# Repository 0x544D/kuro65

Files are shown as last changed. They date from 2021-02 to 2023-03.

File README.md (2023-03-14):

# Kuro65

The hot-swappable ISO mechanical keyboard PCB. 

Features include:
- QMK compatible
- Hot-swappable MX sockets
- 65% ISO DE layout
- Per-key RGB LED
- Multi-layer support

### Table of contents
- [Schematic](#schematic)
- [Bill of Material](#bom)
- [Pictures](#pictures)

# Schematic
<a name="schematic"/>
Standard schematic for a QMK firmware compatible mechanical keyboard.

#### Main schematic:
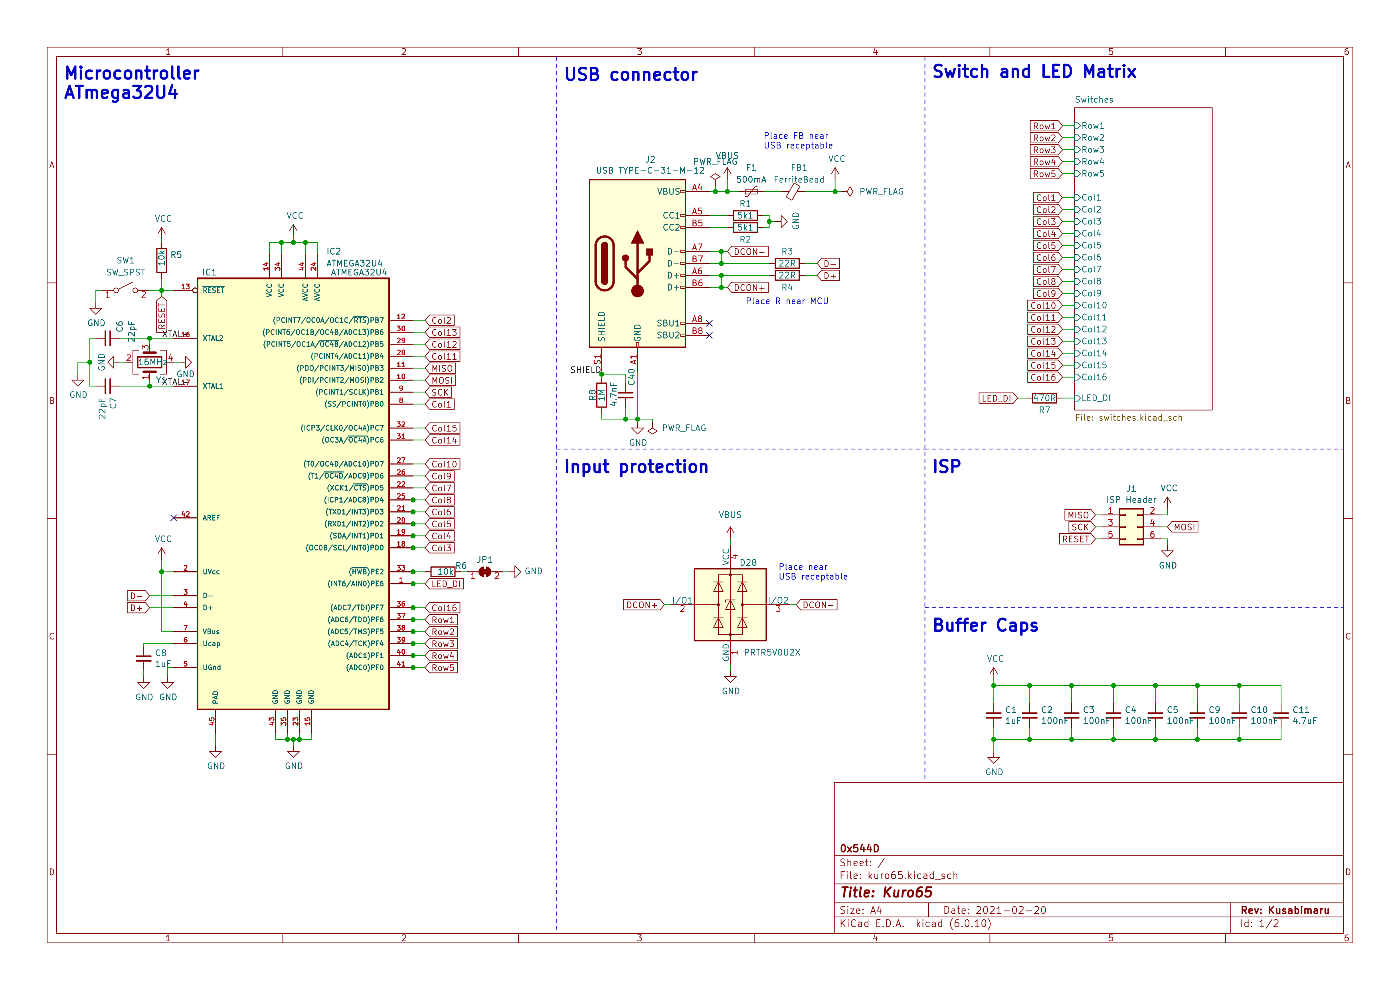
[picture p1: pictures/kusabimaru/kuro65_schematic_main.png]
schematic_main

#### Switch matrix schematic:
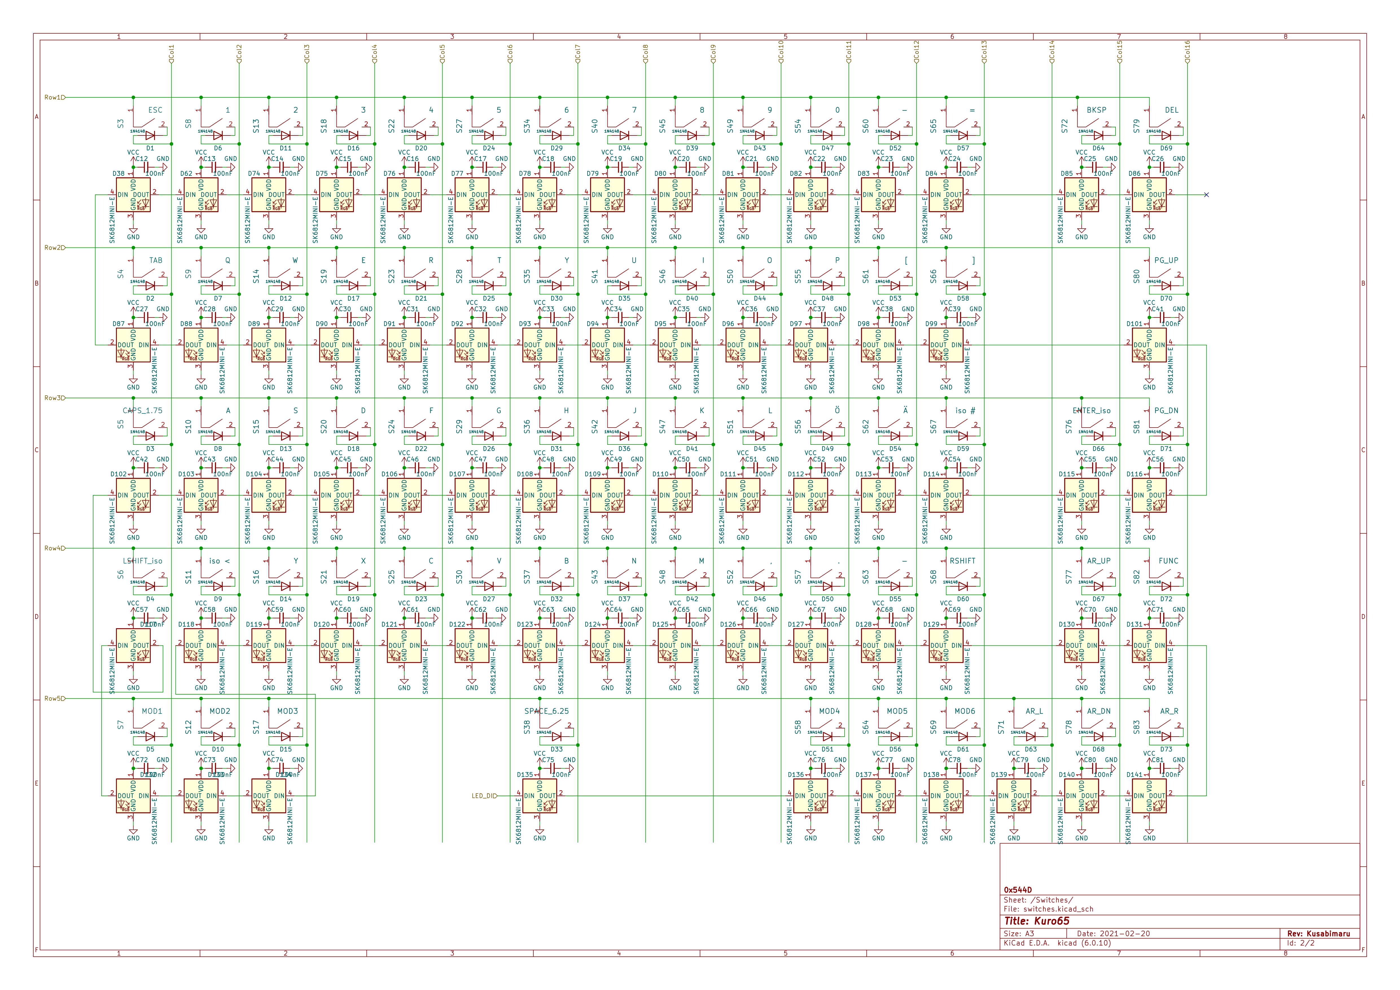
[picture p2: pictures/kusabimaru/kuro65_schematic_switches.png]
schematic_switches


# Bill of Material
<a name="bom"/>

| Qty | Component | Footprint | JLC Part Number | Datasheet | Shop URL |
|-----|---|---|---|---|---|
|  1  | ATMEGA32U4-MU | QFN-44_7x7x05P | C112161 |[Datasheet](https://datasheet.lcsc.com/lcsc/1809032024_Microchip-Tech-ATMEGA32U4-MU_C112161.pdf) | [Link](https://jlcpcb.com/partdetail/MicrochipTech-ATMEGA32U4MU/C112161) |
|  1  | X322516MLB4SI | SMD3225-4P | C13738 |[Datasheet](https://datasheet.lcsc.com/lcsc/2103291133_Yangxing-Tech-X322516MLB4SI_C13738.pdf) | [Link](https://jlcpcb.com/partdetail/YangxingTech-X322516MLB4SI/C13738) |
|  1  | B3FS-1000P | SMD,6x6x3.1mm  | C271750 |[Datasheet](https://omronfs.omron.com/en_US/ecb/products/pdf/en-b3fs.pdf) | [Link](https://jlcpcb.com/partdetail/OmronElectronics-B3FS1000P/C271750) |
|  1  | TYPE-C-31-M-12  | SMD | C165948 |[Datasheet](https://datasheet.lcsc.com/lcsc/2205251630_Korean-Hroparts-Elec-TYPE-C-31-M-12_C165948.pdf) | [Link](https://jlcpcb.com/partdetail/Korean_HropartsElec-TYPE_C_31_M12/C165948) |
| 70  | CPG151101S11 | SMD | C2803348 |[Datasheet](https://datasheet.lcsc.com/lcsc/2202281830_Kailh-CPG151101S11_C2803348.pdf) | [Link](https://jlcpcb.com/partdetail/Kailh-CPG151101S11/C2803348) |
| 70  | 1N4148W | SOD-123 | C109203 |[Datasheet](https://datasheet.lcsc.com/lcsc/1811131721_Shikues-1N4148W_C109203.pdf) | [Link](https://jlcpcb.com/partdetail/Shikues-1N4148W/C109203) |

# Pictures
<a name="pictures"/>

Kuro65 PCB
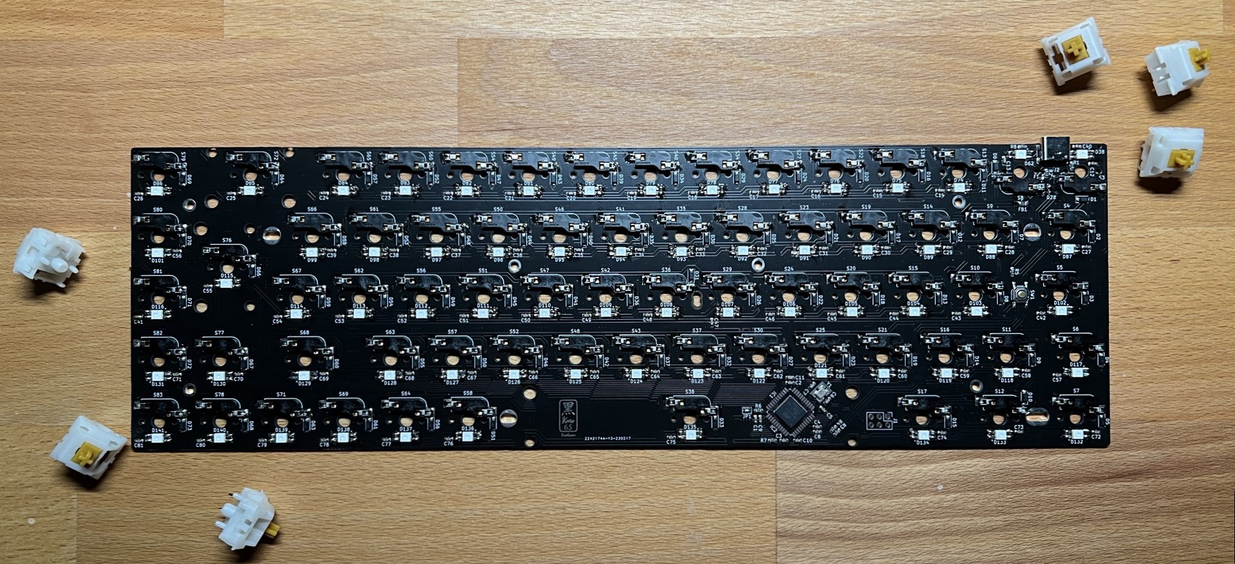
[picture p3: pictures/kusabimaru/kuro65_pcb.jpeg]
kuro65_pcb

Kuro65 inside TOFU65 case
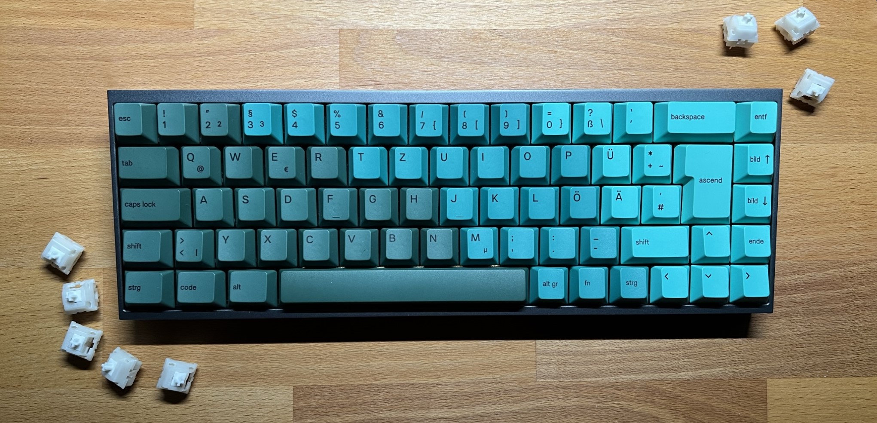
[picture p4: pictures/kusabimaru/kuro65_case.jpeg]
kuro65_case


# Contributors and Acknowledgements
- Keyswitches based on: [daprice](https://github.com/daprice/keyswitches.pretty)
- Stabilizers used: [perigoso](https://github.com/perigoso/Switch_Keyboard)

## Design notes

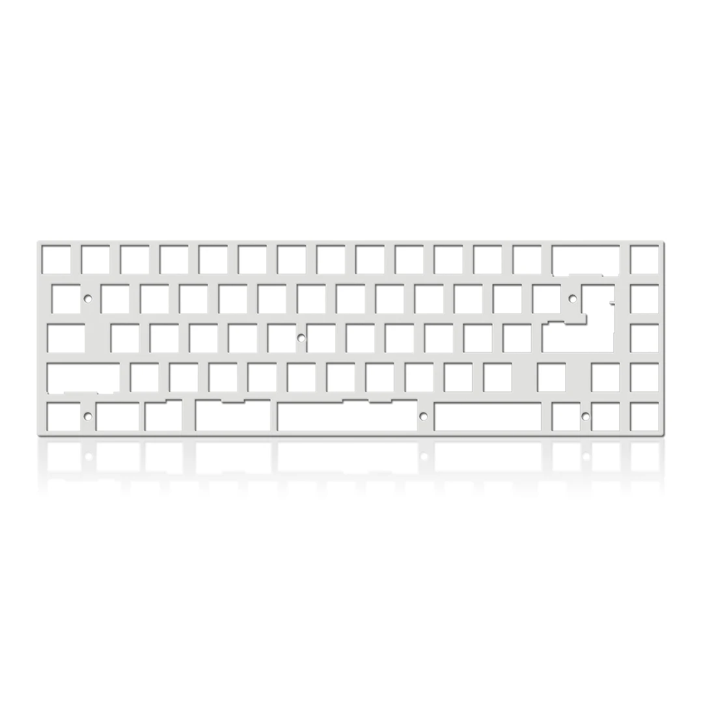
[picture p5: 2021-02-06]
references/65plate.webp

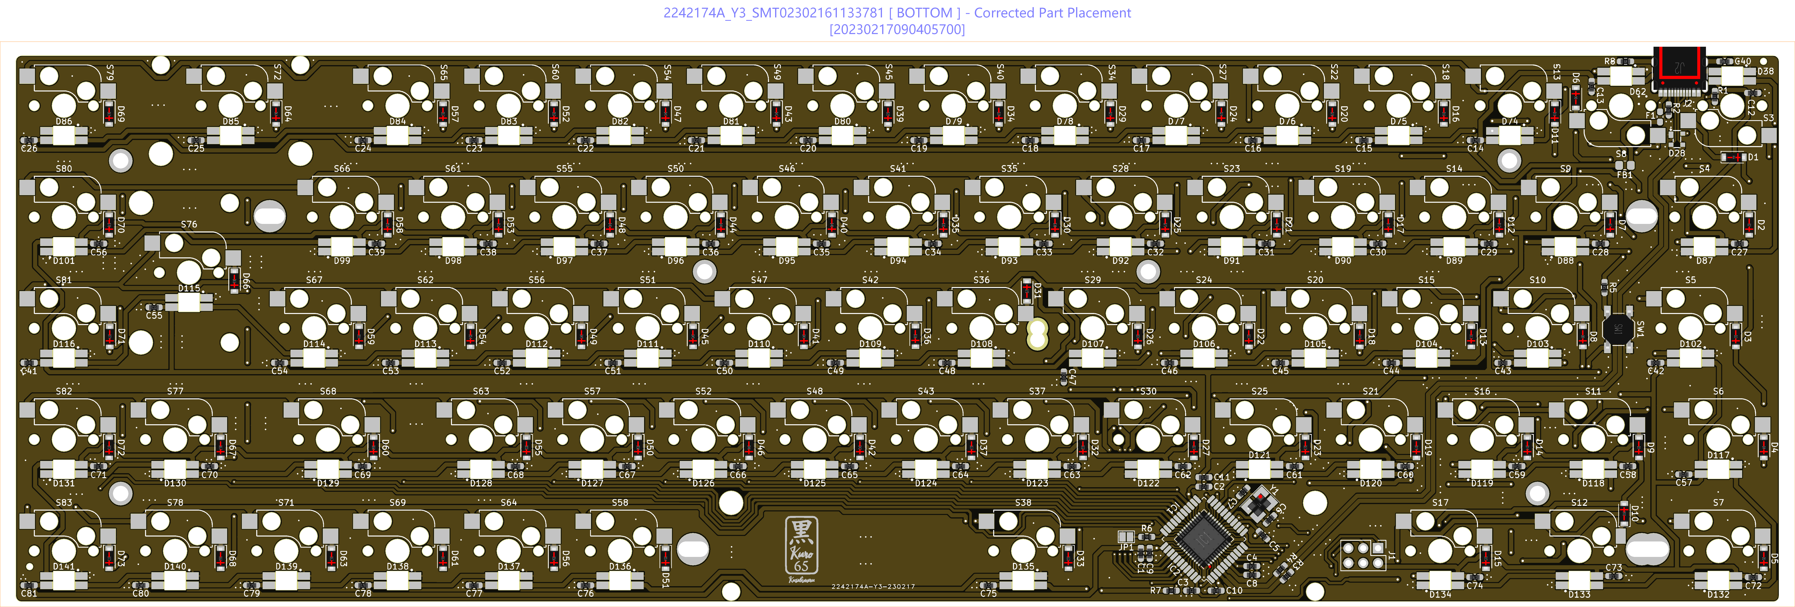
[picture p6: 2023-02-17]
kusabimaru/gerbers/JLCPCB_confirmed_placement.jpg

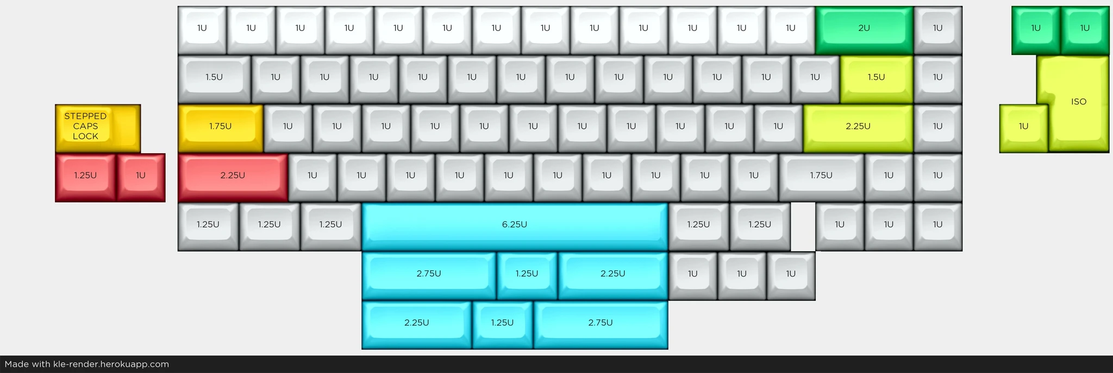
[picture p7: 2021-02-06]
references/KeyLayoutPossible.webp

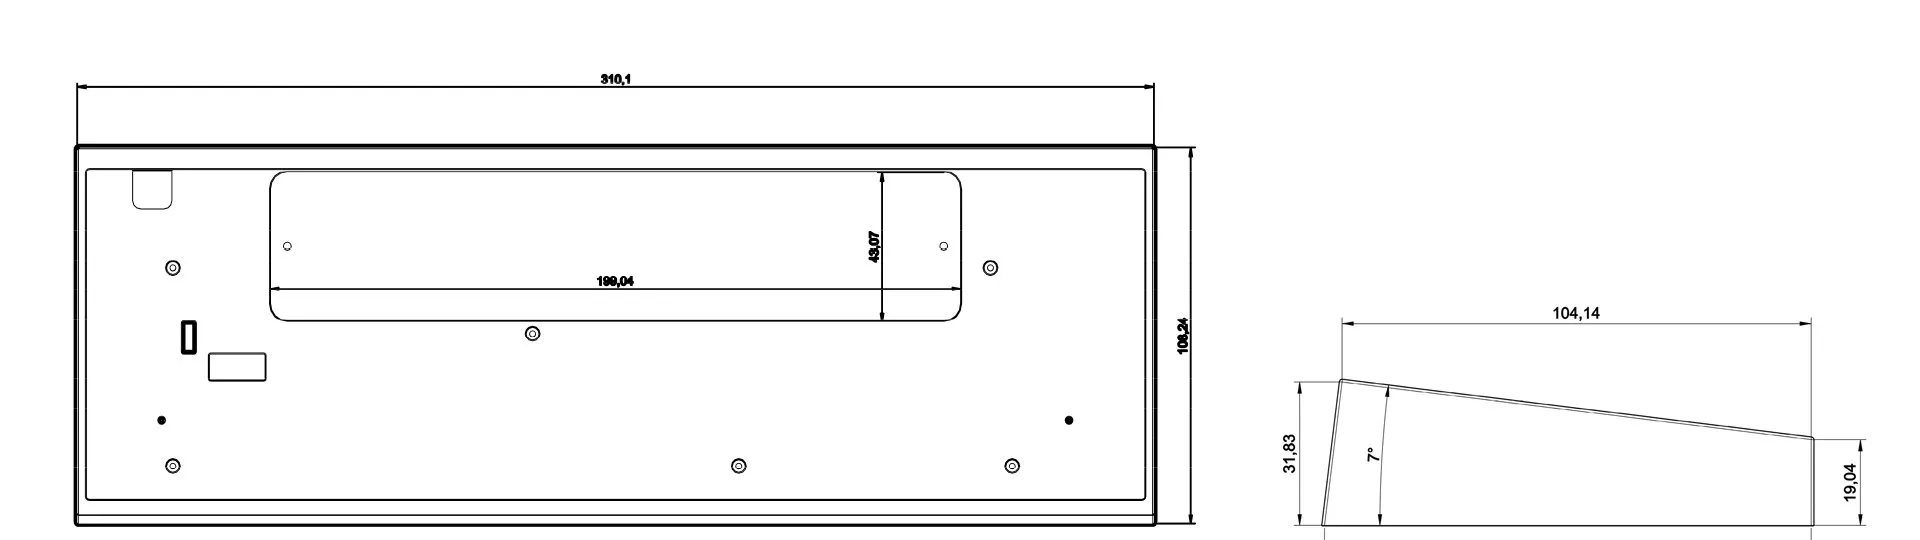
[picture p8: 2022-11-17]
references/Tofu65Dimension.jpg

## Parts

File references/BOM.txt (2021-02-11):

Bill of Material
----------------

USB C Connector:
USB4085-GF-A
https://www.digikey.de/product-detail/de/gct/USB4085-GF-A/2073-USB4085-GF-ACT-ND/9859733
Drawing: https://gct.co/files/drawings/usb4085.pdf

Crystal:
TSX-3225 16.0000MF18X-AC0
https://www.digikey.de/product-detail/de/epson/TSX-3225-16-0000MF18X-AC0/SER4070CT-ND/5413939

Switch:
Omron B3FS-1000
https://de.farnell.com/omron/b3fs-1000/taster-0-05a-24v-dc-beleuchtet/dp/3121161?st=omron%20b3fs

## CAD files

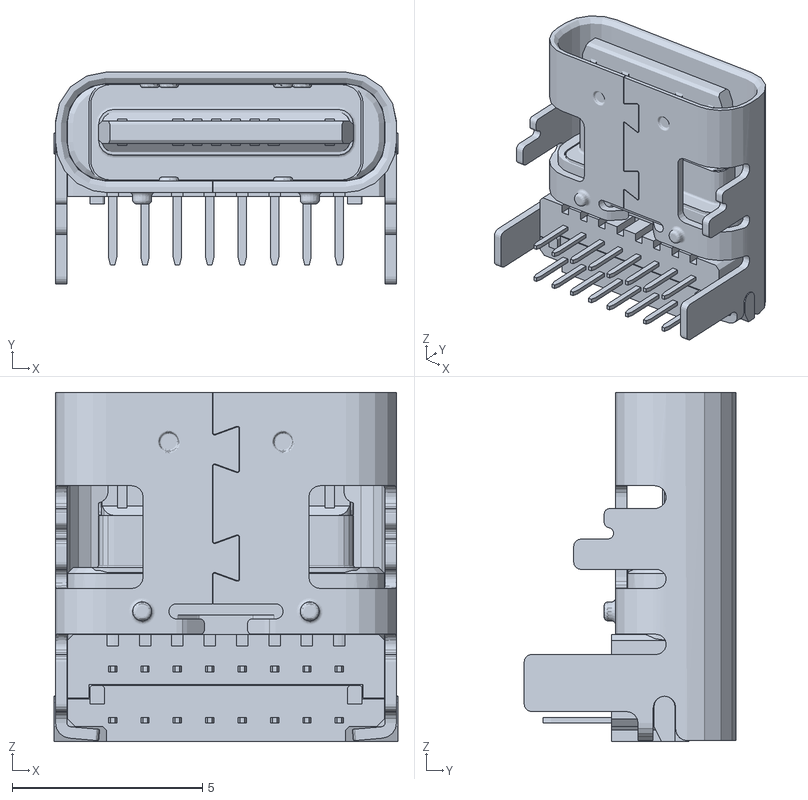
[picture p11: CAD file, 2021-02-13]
3d_models/USB4085-GF-A.stl
9.03 x 5.56 x 9.17

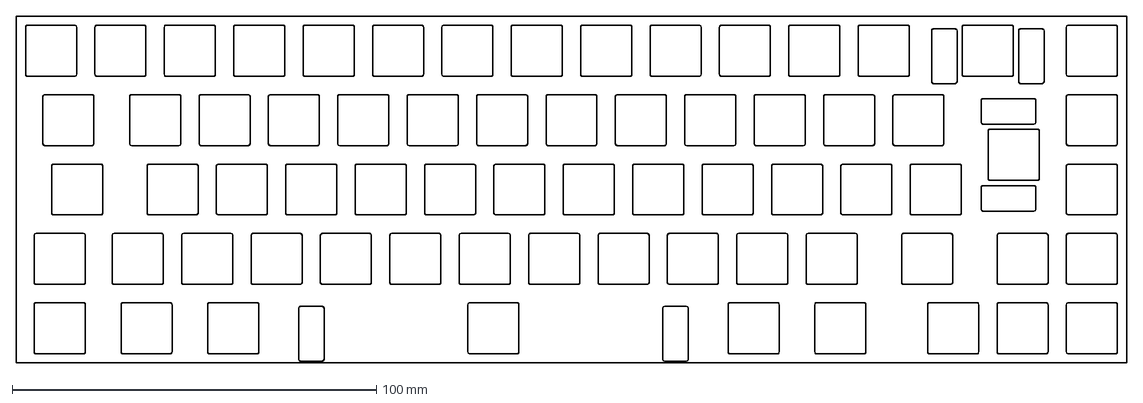
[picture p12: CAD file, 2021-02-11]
plate/plate-65.dxf
304.8 x 95.2 mm

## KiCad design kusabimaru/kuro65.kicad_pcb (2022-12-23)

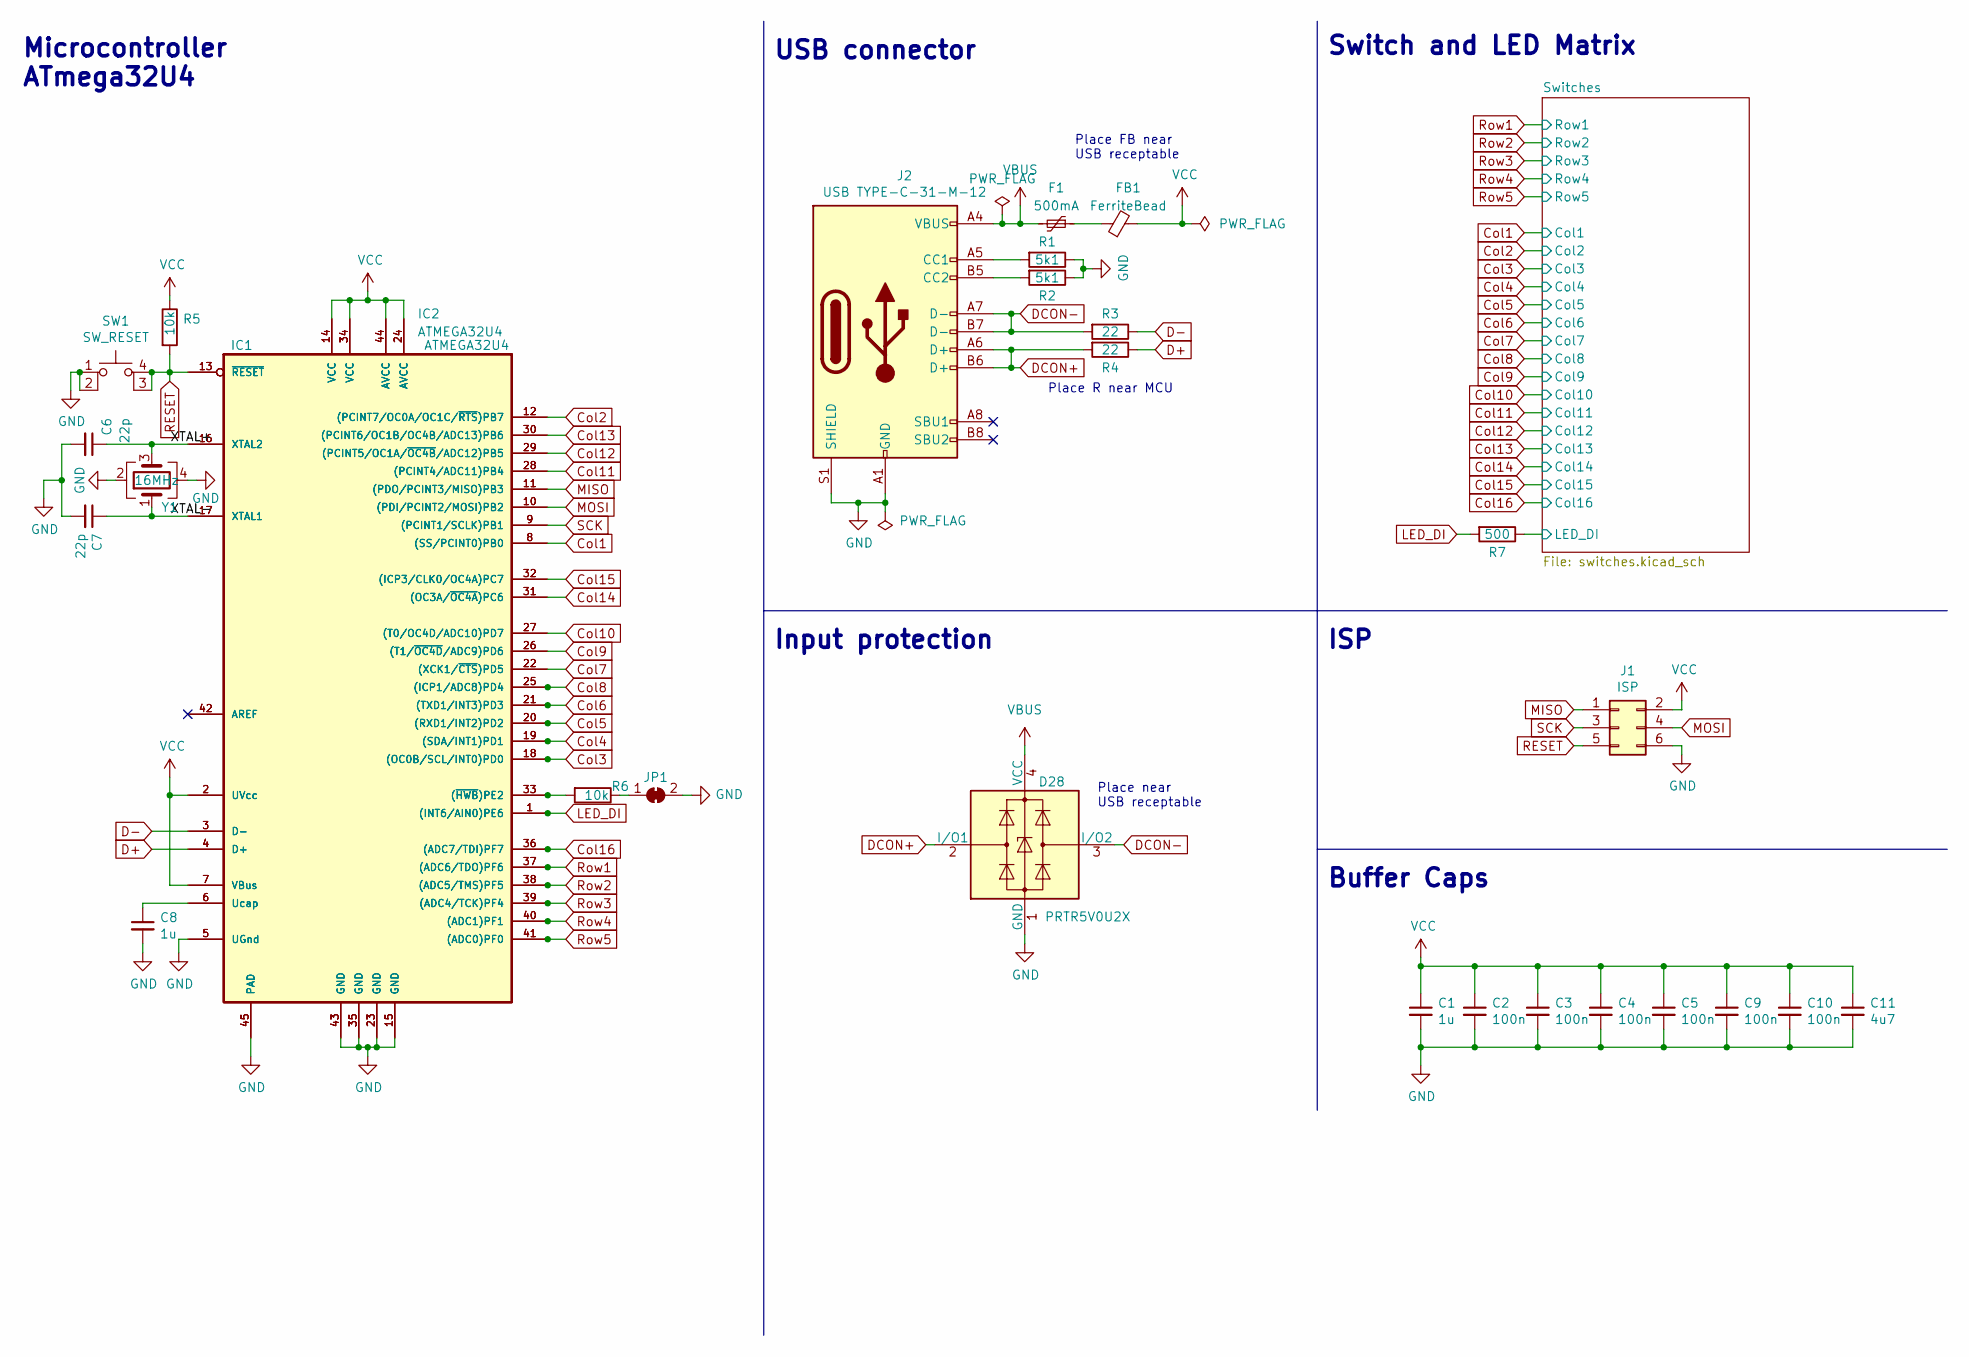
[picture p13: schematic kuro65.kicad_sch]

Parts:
C1, C8: 1u; C_0603_1608Metric_Pad1.08x0.95mm_HandSolder
C2, C3, C4, C5, C9, C10: 100n; C_0603_1608Metric_Pad1.08x0.95mm_HandSolder
C6, C7: 22p; C_0603_1608Metric_Pad1.08x0.95mm_HandSolder
C11: 4u7; C_0603_1608Metric_Pad1.08x0.95mm_HandSolder
D28: PRTR5V0U2X; SOT-143
F1: 500mA; Fuse_0603_1608Metric_Pad1.05x0.95mm_HandSolder
FB1: FerriteBead; R_0805_2012Metric_Pad1.20x1.40mm_HandSolder
IC1: ATMEGA32U4; QFN-44-1EP_7x7mm_P0.5mm_EP5.2x5.2mm_ThermalVias
IC2: ATMEGA32U4; LQFP-44_10x10mm_P0.8mm
J1: ISP; PinHeader_2x03_P2.54mm_Vertical
J2: USB TYPE-C-31-M-12; USB_C_Receptacle_HRO_TYPE-C-31-M-12
JP1: SolderJumper_2_Bridged; SolderJumper-2_P1.3mm_Open_Pad1.0x1.5mm
R1, R2: 5k1; R_0603_1608Metric_Pad0.98x0.95mm_HandSolder
R3, R4: 22; R_0603_1608Metric_Pad0.98x0.95mm_HandSolder
R5, R6: 10k; R_0603_1608Metric_Pad0.98x0.95mm_HandSolder
R7: 500; R_0603_1608Metric_Pad0.98x0.95mm_HandSolder
SW1: SW_RESET; SW_SPST_Omron_B3FS-100xP
Y1: 16MHz; Crystal_SMD_SeikoEpson_TSX3225-4Pin_3.2x2.5mm_HandSoldering

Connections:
/Switches/LED_DI: R7.1; also elsewhere on the board
/XTAL+: C6.1, IC1.16 (XTAL2), IC2.16 (XTAL2), Y1.3
/XTAL-: C7.1, IC1.17 (XTAL1), IC2.17 (XTAL1), Y1.1
Col1: IC1.8 ((SS/PCINT0)PB0), IC2.8 ((SS/PCINT0)PB0); also elsewhere on the board
Col2: IC1.12 ((PCINT7/OC0A/OC1C/~RTS)PB7), IC2.12 ((PCINT7/OC0A/OC1C/~RTS)PB7); also elsewhere on the board
Col3: IC1.18 ((OC0B/SCL/INT0)PD0), IC2.18 ((OC0B/SCL/INT0)PD0); also elsewhere on the board
Col4: IC1.19 ((SDA/INT1)PD1), IC2.19 ((SDA/INT1)PD1); also elsewhere on the board
Col5: IC1.20 ((RXD1/INT2)PD2), IC2.20 ((RXD1/INT2)PD2); also elsewhere on the board
Col6: IC1.21 ((TXD1/INT3)PD3), IC2.21 ((TXD1/INT3)PD3); also elsewhere on the board
Col7: IC1.22 ((XCK1/~CTS)PD5), IC2.22 ((XCK1/~CTS)PD5); also elsewhere on the board
Col8: IC1.25 ((ICP1/ADC8)PD4), IC2.25 ((ICP1/ADC8)PD4); also elsewhere on the board
Col9: IC1.26 ((T1/~OC4D/ADC9)PD6), IC2.26 ((T1/~OC4D/ADC9)PD6); also elsewhere on the board
Col10: IC1.27 ((T0/OC4D/ADC10)PD7), IC2.27 ((T0/OC4D/ADC10)PD7); also elsewhere on the board
Col11: IC1.28 ((PCINT4/ADC11)PB4), IC2.28 ((PCINT4/ADC11)PB4); also elsewhere on the board
Col12: IC1.29 ((PCINT5/OC1A/~OC4B/ADC12)PB5), IC2.29 ((PCINT5/OC1A/~OC4B/ADC12)PB5); also elsewhere on the board
Col13: IC1.30 ((PCINT6/OC1B/OC4B/ADC13)PB6), IC2.30 ((PCINT6/OC1B/OC4B/ADC13)PB6); also elsewhere on the board
Col14: IC1.31 ((OC3A/~OC4A)PC6), IC2.31 ((OC3A/~OC4A)PC6); also elsewhere on the board
Col15: IC1.32 ((ICP3/CLK0/OC4A)PC7), IC2.32 ((ICP3/CLK0/OC4A)PC7); also elsewhere on the board
Col16: IC1.36 ((ADC7/TDI)PF7), IC2.36 ((ADC7/TDI)PF7); also elsewhere on the board
D+: IC1.4 (D+), IC2.4 (D+), R4.1
D-: IC1.3 (D-), IC2.3 (D-), R3.1
DCON+: D28.2 (I/O1), J2.A6 (D+), J2.B6 (D+), R4.2
DCON-: D28.3 (I/O2), J2.A7 (D-), J2.B7 (D-), R3.2
GND: C1.2, C2.2, C3.2, C4.2, C5.2, C6.2, C7.2, C8.2, C9.2, C10.2, C11.2, D28.1 (GND), IC1.5 (UGnd), IC1.15 (GND), IC1.23 (GND), IC1.35 (GND), IC1.43 (GND), IC1.45 (PAD), IC2.5 (UGnd), IC2.15 (GND), IC2.23 (GND), IC2.35 (GND), IC2.43 (GND), IC2.45 (PAD), J1.6, J2.A1 (GND), J2.A12 (GND), J2.B1 (GND), J2.B12 (GND), J2.S1 (SHIELD), JP1.2 (B), R1.1, R2.1, SW1.1, SW1.2, Y1.2, Y1.4; also elsewhere on the board
LED_DI: IC1.1 ((INT6/AIN0)PE6), IC2.1 ((INT6/AIN0)PE6), R7.2
MISO: IC1.11 ((PDO/PCINT3/MISO)PB3), IC2.11 ((PDO/PCINT3/MISO)PB3), J1.1
MOSI: IC1.10 ((PDI/PCINT2/MOSI)PB2), IC2.10 ((PDI/PCINT2/MOSI)PB2), J1.4
unnamed: C8.1, IC1.6 (Ucap), IC2.6 (Ucap)
unnamed: F1.1, FB1.1
unnamed: IC1.33 ((~HWB)PE2), IC2.33 ((~HWB)PE2), R6.2
unnamed: J2.A5 (CC1), R1.2
unnamed: J2.B5 (CC2), R2.2
unnamed: JP1.1 (A), R6.1
RESET: IC1.13 (~RESET), IC2.13 (~RESET), J1.5, R5.2, SW1.3 (K), SW1.4 (A)
Row1: IC1.37 ((ADC6/TDO)PF6), IC2.37 ((ADC6/TDO)PF6); also elsewhere on the board
Row2: IC1.38 ((ADC5/TMS)PF5), IC2.38 ((ADC5/TMS)PF5); also elsewhere on the board
Row3: IC1.39 ((ADC4/TCK)PF4), IC2.39 ((ADC4/TCK)PF4); also elsewhere on the board
Row4: IC1.40 ((ADC1)PF1), IC2.40 ((ADC1)PF1); also elsewhere on the board
Row5: IC1.41 ((ADC0)PF0), IC2.41 ((ADC0)PF0); also elsewhere on the board
SCK: IC1.9 ((PCINT1/SCLK)PB1), IC2.9 ((PCINT1/SCLK)PB1), J1.3
VBUS: D28.4 (VCC), F1.2, J2.A4 (VBUS), J2.A9 (VBUS), J2.B4 (VBUS), J2.B9 (VBUS)
VCC: C1.1, C2.1, C3.1, C4.1, C5.1, C9.1, C10.1, C11.1, FB1.2, IC1.2 (UVcc), IC1.7 (VBus), IC1.14 (VCC), IC1.24 (AVCC), IC1.34 (VCC), IC1.44 (AVCC), IC2.2 (UVcc), IC2.7 (VBus), IC2.14 (VCC), IC2.24 (AVCC), IC2.34 (VCC), IC2.44 (AVCC), J1.2, R5.1; also elsewhere on the board

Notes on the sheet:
Buffer Caps
USB connector
Place FB near USB receptable
Input protection
Place R near MCU
ISP
Switch and LED Matrix
Place near USB receptable
Microcontroller ATmega32U4

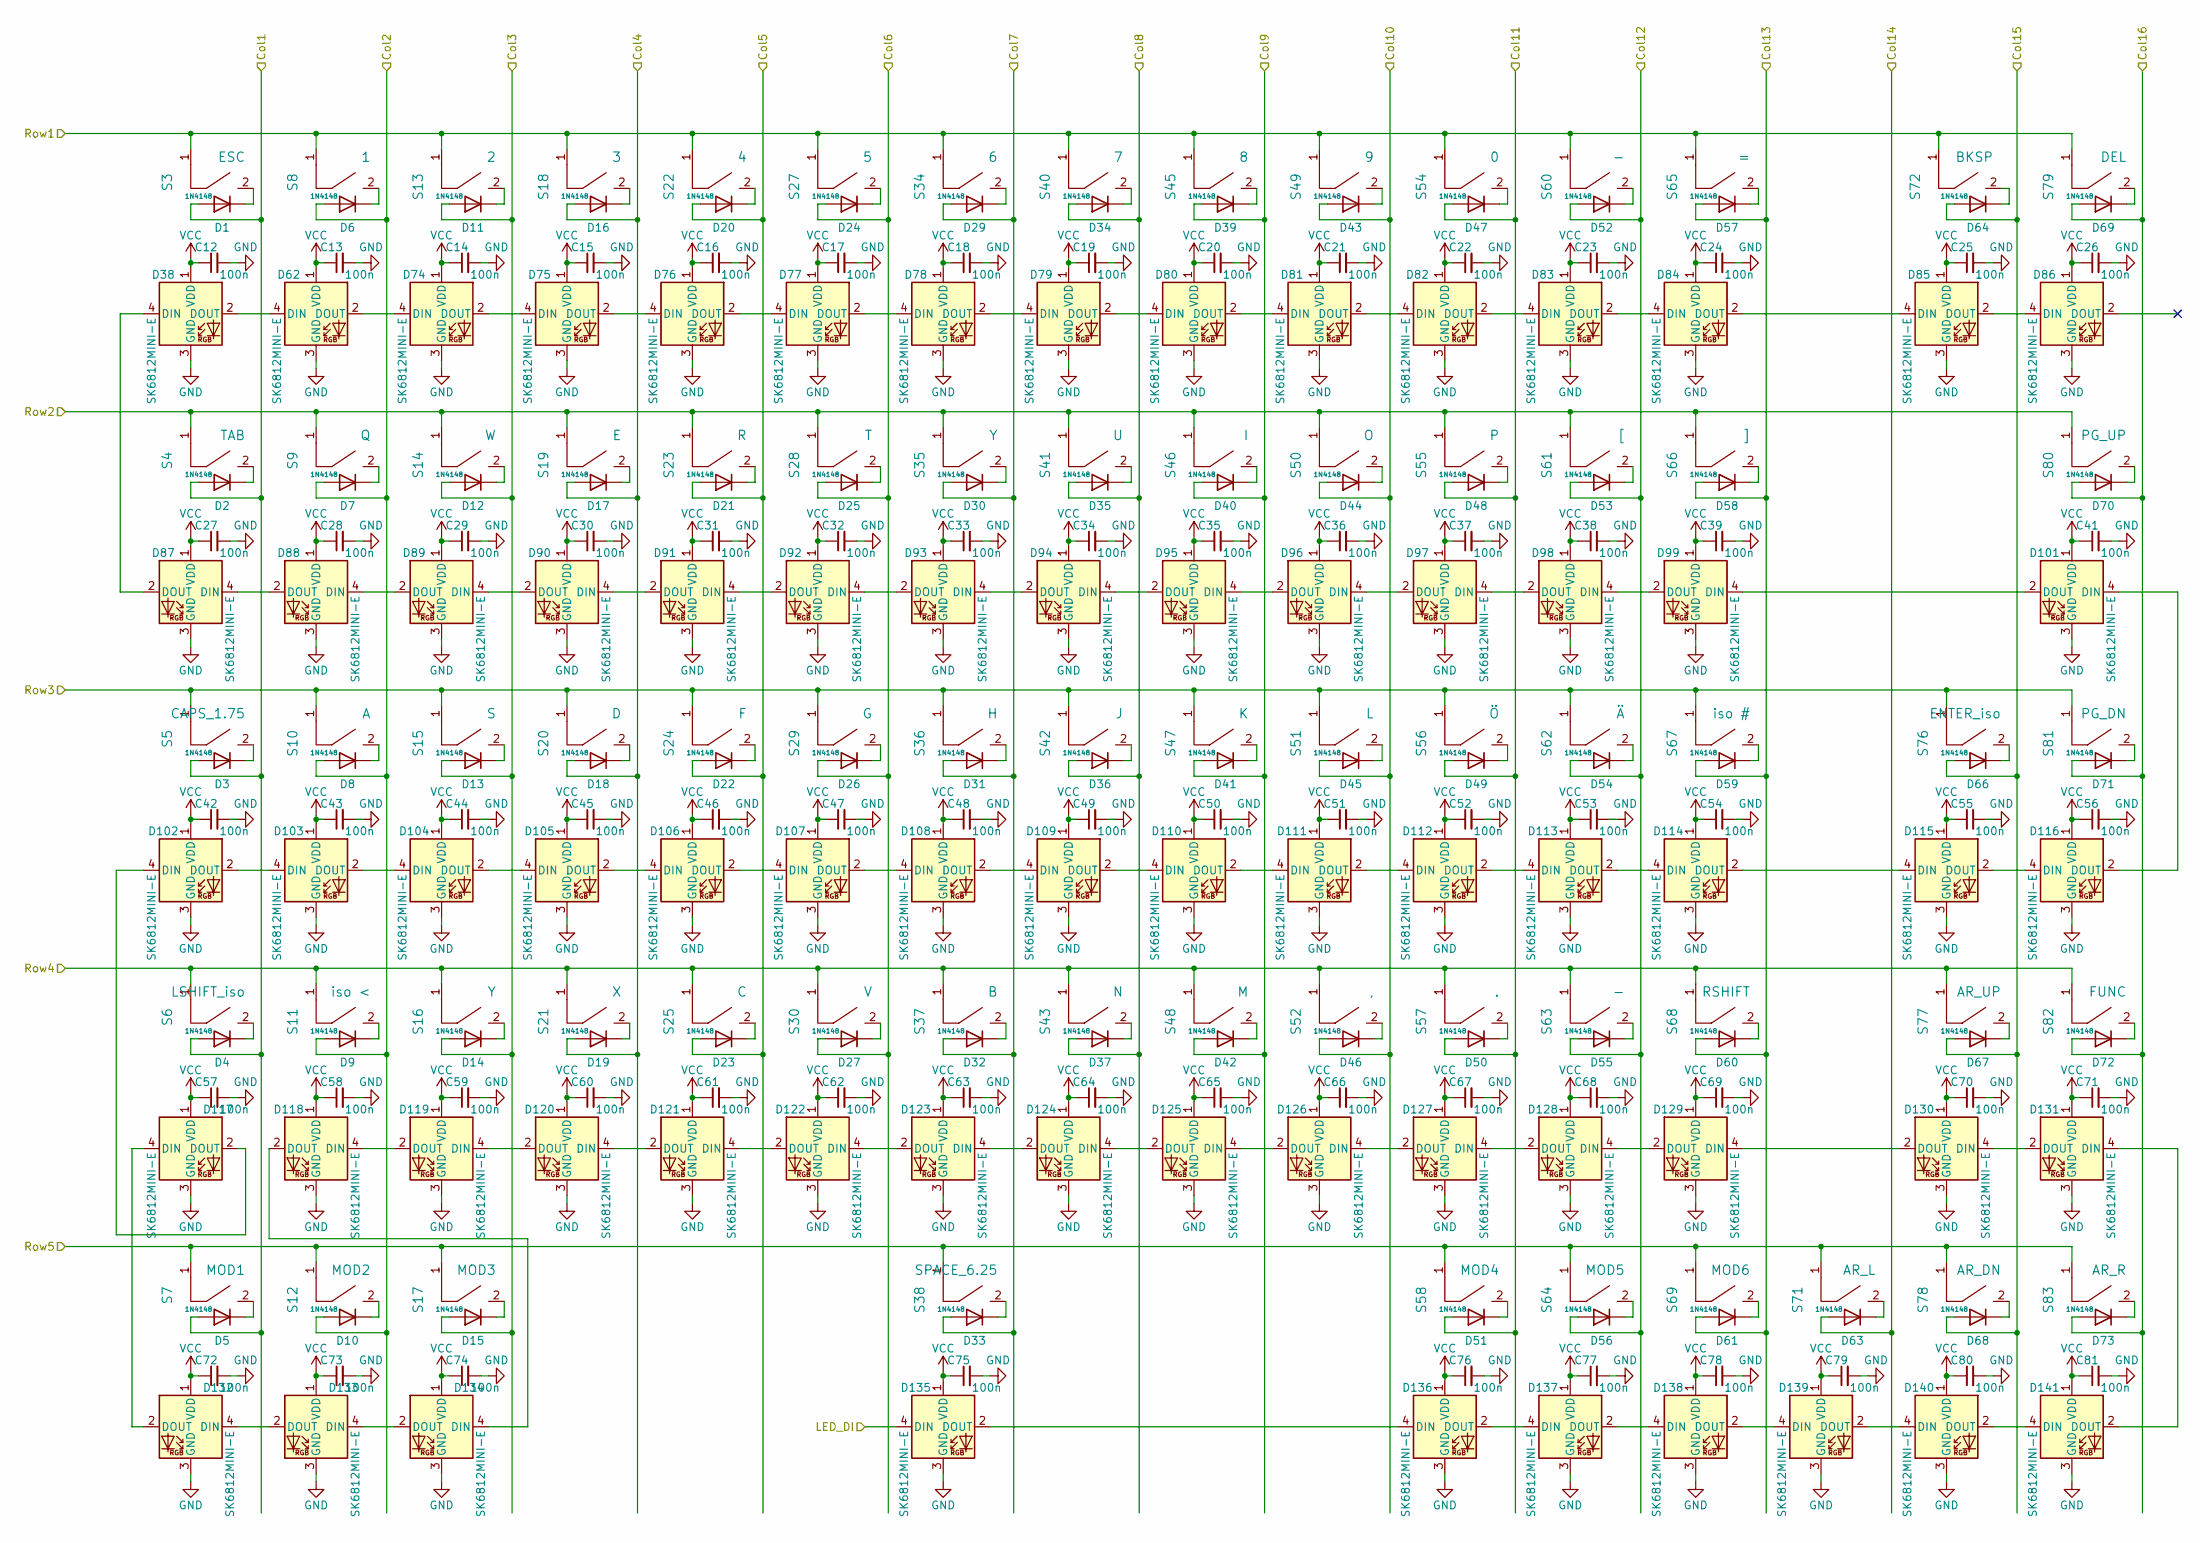
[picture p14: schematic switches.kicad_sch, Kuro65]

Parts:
C12, C13, C14, C15, C16, C17, C18, C19, C20, C21, C22, C23, C24, C25, C26, C27, C28, C29, C30, C31, C32, C33, C34, C35, C36, C37, C38, C39, C41, C42, C43, C44, C45, C46, C47, C48, C49, C50, C51, C52, C53, C54, C55, C56, C57, C58, C59, C60, C61, C62, C63, C64, C65, C66, C67, C68, C69, C70, C71, C72, C73, C74, C75, C76, C77, C78, C79, C80, C81: 100n; C_0603_1608Metric_Pad1.08x0.95mm_HandSolder
D1, D2, D3, D4, D5, D6, D7, D8, D9, D10, D11, D12, D13, D14, D15, D16, D17, D18, D19, D20, D21, D22, D23, D24, D25, D26, D27, D29, D30, D31, D32, D33, D34, D35, D36, D37, D39, D40, D41, D42, D43, D44, D45, D46, D47, D48, D49, D50, D51, D52, D53, D54, D55, D56, D57, D58, D59, D60, D61, D63, D64, D66, D67, D68, D69, D70, D71, D72, D73: 1N4148; D_SOD-123
D38, D62, D74, D75, D76, D77, D78, D79, D80, D81, D82, D83, D84, D85, D86, D87, D88, D89, D90, D91, D92, D93, D94, D95, D96, D97, D98, D99, D101, D102, D103, D104, D105, D106, D107, D108, D109, D110, D111, D112, D113, D114, D115, D116, D117, D118, D119, D120, D121, D122, D123, D124, D125, D126, D127, D128, D129, D130, D131, D132, D133, D134, D135, D136, D137, D138, D139, D140, D141: SK6812MINI-E; SK6812_MINI_E_small_cutout
S3: ESC; Kailh_socket_only_MX_smd_1u
S4: TAB; Kailh_socket_only_MX_smd_1.5u
S5: CAPS_1.75; Kailh_socket_only_MX_smd_1.75u
S6: LSHIFT_iso; Kailh_socket_only_MX_smd_1.25u
S7: MOD1; Kailh_socket_only_MX_smd_1.25u
S8: 1; Kailh_socket_only_MX_smd_1u
S9: Q; Kailh_socket_only_MX_smd_1u
S10: A; Kailh_socket_only_MX_smd_1u
S11: iso <; Kailh_socket_only_MX_smd_1u
S12: MOD2; Kailh_socket_only_MX_smd_1.25u
S13: 2; Kailh_socket_only_MX_smd_1u
S14: W; Kailh_socket_only_MX_smd_1u
S15: S; Kailh_socket_only_MX_smd_1u
S16, S35: Y; Kailh_socket_only_MX_smd_1u
S17: MOD3; Kailh_socket_only_MX_smd_1.25u
S18: 3; Kailh_socket_only_MX_smd_1u
S19: E; Kailh_socket_only_MX_smd_1u
S20: D; Kailh_socket_only_MX_smd_1u
S21: X; Kailh_socket_only_MX_smd_1u
S22: 4; Kailh_socket_only_MX_smd_1u
S23: R; Kailh_socket_only_MX_smd_1u
S24: F; Kailh_socket_only_MX_smd_1u
S25: C; Kailh_socket_only_MX_smd_1u
S27: 5; Kailh_socket_only_MX_smd_1u
S28: T; Kailh_socket_only_MX_smd_1u
S29: G; Kailh_socket_only_MX_smd_1u
S30: V; Kailh_socket_only_MX_smd_1u
S34: 6; Kailh_socket_only_MX_smd_1u
S36: H; Kailh_socket_only_MX_smd_1u
S37: B; Kailh_socket_only_MX_smd_1u
S38: SPACE_6.25; Kailh_socket_only_MX_smd_6.25u
S40: 7; Kailh_socket_only_MX_smd_1u
S41: U; Kailh_socket_only_MX_smd_1u
S42: J; Kailh_socket_only_MX_smd_1u
S43: N; Kailh_socket_only_MX_smd_1u
S45: 8; Kailh_socket_only_MX_smd_1u
S46: I; Kailh_socket_only_MX_smd_1u
S47: K; Kailh_socket_only_MX_smd_1u
S48: M; Kailh_socket_only_MX_smd_1u
S49: 9; Kailh_socket_only_MX_smd_1u
S50: O; Kailh_socket_only_MX_smd_1u
S51: L; Kailh_socket_only_MX_smd_1u
S52: ,; Kailh_socket_only_MX_smd_1u
S54: 0; Kailh_socket_only_MX_smd_1u
S55: P; Kailh_socket_only_MX_smd_1u
S56: Ö; Kailh_socket_only_MX_smd_1u
S57: .; Kailh_socket_only_MX_smd_1u
S58: MOD4; Kailh_socket_only_MX_smd_1u
S60, S63: -; Kailh_socket_only_MX_smd_1u
S61: [; Kailh_socket_only_MX_smd_1u
S62: Ä; Kailh_socket_only_MX_smd_1u
S64: MOD5; Kailh_socket_only_MX_smd_1u
S65: =; Kailh_socket_only_MX_smd_1u
S66: ]; Kailh_socket_only_MX_smd_1u
S67: iso #; Kailh_socket_only_MX_smd_1u
S68: RSHIFT; Kailh_socket_only_MX_smd_1.75u
S69: MOD6; Kailh_socket_only_MX_smd_1u
S71: AR_L; Kailh_socket_only_MX_smd_1u
S72: BKSP; Kailh_socket_only_MX_smd_2u
S76: ENTER_iso; Kailh_socket_only_MX_smd_iso_enter
S77: AR_UP; Kailh_socket_only_MX_smd_1u
S78: AR_DN; Kailh_socket_only_MX_smd_1u
S79: DEL; Kailh_socket_only_MX_smd_1u
S80: PG_UP; Kailh_socket_only_MX_smd_1u
S81: PG_DN; Kailh_socket_only_MX_smd_1u
S82: FUNC; Kailh_socket_only_MX_smd_1u
S83: AR_R; Kailh_socket_only_MX_smd_1u

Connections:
/Switches/LED_DI: D135.4 (DIN); also elsewhere on the board
Col1: D1.2 (A), D2.2 (A), D3.2 (A), D4.2 (A), D5.2 (A); also elsewhere on the board
Col2: D6.2 (A), D7.2 (A), D8.2 (A), D9.2 (A), D10.2 (A); also elsewhere on the board
Col3: D11.2 (A), D12.2 (A), D13.2 (A), D14.2 (A), D15.2 (A); also elsewhere on the board
Col4: D16.2 (A), D17.2 (A), D18.2 (A), D19.2 (A); also elsewhere on the board
Col5: D20.2 (A), D21.2 (A), D22.2 (A), D23.2 (A); also elsewhere on the board
Col6: D24.2 (A), D25.2 (A), D26.2 (A), D27.2 (A); also elsewhere on the board
Col7: D29.2 (A), D30.2 (A), D31.2 (A), D32.2 (A), D33.2 (A); also elsewhere on the board
Col8: D34.2 (A), D35.2 (A), D36.2 (A), D37.2 (A); also elsewhere on the board
Col9: D39.2 (A), D40.2 (A), D41.2 (A), D42.2 (A); also elsewhere on the board
Col10: D43.2 (A), D44.2 (A), D45.2 (A), D46.2 (A); also elsewhere on the board
Col11: D47.2 (A), D48.2 (A), D49.2 (A), D50.2 (A), D51.2 (A); also elsewhere on the board
Col12: D52.2 (A), D53.2 (A), D54.2 (A), D55.2 (A), D56.2 (A); also elsewhere on the board
Col13: D57.2 (A), D58.2 (A), D59.2 (A), D60.2 (A), D61.2 (A); also elsewhere on the board
Col14: D63.2 (A); also elsewhere on the board
Col15: D64.2 (A), D66.2 (A), D67.2 (A), D68.2 (A); also elsewhere on the board
Col16: D69.2 (A), D70.2 (A), D71.2 (A), D72.2 (A), D73.2 (A); also elsewhere on the board
GND: C12.2, C13.2, C14.2, C15.2, C16.2, C17.2, C18.2, C19.2, C20.2, C21.2, C22.2, C23.2, C24.2, C25.2, C26.2, C27.2, C28.2, C29.2, C30.2, C31.2, C32.2, C33.2, C34.2, C35.2, C36.2, C37.2, C38.2, C39.2, C41.2, C42.2, C43.2, C44.2, C45.2, C46.2, C47.2, C48.2, C49.2, C50.2, C51.2, C52.2, C53.2, C54.2, C55.2, C56.2, C57.2, C58.2, C59.2, C60.2, C61.2, C62.2, C63.2, C64.2, C65.2, C66.2, C67.2, C68.2, C69.2, C70.2, C71.2, C72.2, C73.2, C74.2, C75.2, C76.2, C77.2, C78.2, C79.2, C80.2, C81.2, D38.3 (GND), D62.3 (GND), D74.3 (GND), D75.3 (GND), D76.3 (GND), D77.3 (GND), D78.3 (GND), D79.3 (GND), D80.3 (GND), D81.3 (GND), D82.3 (GND), D83.3 (GND), D84.3 (GND), D85.3 (GND), D86.3 (GND), D87.3 (GND), D88.3 (GND), D89.3 (GND), D90.3 (GND), D91.3 (GND), D92.3 (GND), D93.3 (GND), D94.3 (GND), D95.3 (GND), D96.3 (GND), D97.3 (GND), D98.3 (GND), D99.3 (GND), D101.3 (GND), D102.3 (GND), D103.3 (GND), D104.3 (GND), D105.3 (GND), D106.3 (GND), D107.3 (GND), D108.3 (GND), D109.3 (GND), D110.3 (GND), D111.3 (GND), D112.3 (GND), D113.3 (GND), D114.3 (GND), D115.3 (GND), D116.3 (GND), D117.3 (GND), D118.3 (GND), D119.3 (GND), D120.3 (GND), D121.3 (GND), D122.3 (GND), D123.3 (GND), D124.3 (GND), D125.3 (GND), D126.3 (GND), D127.3 (GND), D128.3 (GND), D129.3 (GND), D130.3 (GND), D131.3 (GND), D132.3 (GND), D133.3 (GND), D134.3 (GND), D135.3 (GND), D136.3 (GND), D137.3 (GND), D138.3 (GND), D139.3 (GND), D140.3 (GND), D141.3 (GND); also elsewhere on the board
unnamed: D1.1 (K), S3.2
unnamed: D2.1 (K), S4.2
unnamed: D3.1 (K), S5.2
unnamed: D4.1 (K), S6.2
unnamed: D5.1 (K), S7.2
unnamed: D6.1 (K), S8.2
unnamed: D7.1 (K), S9.2
unnamed: D8.1 (K), S10.2
unnamed: D9.1 (K), S11.2
unnamed: D10.1 (K), S12.2
unnamed: D11.1 (K), S13.2
unnamed: D12.1 (K), S14.2
unnamed: D13.1 (K), S15.2
unnamed: D14.1 (K), S16.2
unnamed: D15.1 (K), S17.2
unnamed: D16.1 (K), S18.2
unnamed: D17.1 (K), S19.2
unnamed: D18.1 (K), S20.2
unnamed: D19.1 (K), S21.2
unnamed: D20.1 (K), S22.2
unnamed: D21.1 (K), S23.2
unnamed: D22.1 (K), S24.2
unnamed: D23.1 (K), S25.2
unnamed: D24.1 (K), S27.2
unnamed: D25.1 (K), S28.2
unnamed: D26.1 (K), S29.2
unnamed: D27.1 (K), S30.2
unnamed: D29.1 (K), S34.2
unnamed: D30.1 (K), S35.2
unnamed: D31.1 (K), S36.2
unnamed: D32.1 (K), S37.2
unnamed: D33.1 (K), S38.2
unnamed: D34.1 (K), S40.2
unnamed: D35.1 (K), S41.2
unnamed: D36.1 (K), S42.2
unnamed: D37.1 (K), S43.2
unnamed: D38.2 (DOUT), D62.4 (DIN)
unnamed: D39.1 (K), S45.2
unnamed: D40.1 (K), S46.2
unnamed: D41.1 (K), S47.2
unnamed: D42.1 (K), S48.2
unnamed: D43.1 (K), S49.2
unnamed: D44.1 (K), S50.2
unnamed: D45.1 (K), S51.2
unnamed: D46.1 (K), S52.2
unnamed: D47.1 (K), S54.2
unnamed: D48.1 (K), S55.2
unnamed: D49.1 (K), S56.2
unnamed: D50.1 (K), S57.2
unnamed: D51.1 (K), S58.2
unnamed: D52.1 (K), S60.2
unnamed: D53.1 (K), S61.2
unnamed: D54.1 (K), S62.2
unnamed: D55.1 (K), S63.2
unnamed: D56.1 (K), S64.2
unnamed: D57.1 (K), S65.2
unnamed: D58.1 (K), S66.2
unnamed: D59.1 (K), S67.2
unnamed: D60.1 (K), S68.2
unnamed: D61.1 (K), S69.2
unnamed: D62.2 (DOUT), D74.4 (DIN)
unnamed: D63.1 (K), S71.2
unnamed: D64.1 (K), S72.2
unnamed: D66.1 (K), S76.2
unnamed: D67.1 (K), S77.2
unnamed: D68.1 (K), S78.2
unnamed: D69.1 (K), S79.2
unnamed: D70.1 (K), S80.2
unnamed: D71.1 (K), S81.2
unnamed: D72.1 (K), S82.2
unnamed: D73.1 (K), S83.2
unnamed: D74.2 (DOUT), D75.4 (DIN)
unnamed: D75.2 (DOUT), D76.4 (DIN)
unnamed: D76.2 (DOUT), D77.4 (DIN)
unnamed: D77.2 (DOUT), D78.4 (DIN)
unnamed: D78.2 (DOUT), D79.4 (DIN)
unnamed: D79.2 (DOUT), D80.4 (DIN)
unnamed: D80.2 (DOUT), D81.4 (DIN)
unnamed: D81.2 (DOUT), D82.4 (DIN)
unnamed: D82.2 (DOUT), D83.4 (DIN)
unnamed: D83.2 (DOUT), D84.4 (DIN)
unnamed: D84.2 (DOUT), D85.4 (DIN)
unnamed: D85.2 (DOUT), D86.4 (DIN)
unnamed: D38.4 (DIN), D87.2 (DOUT)
unnamed: D87.4 (DIN), D88.2 (DOUT)
unnamed: D88.4 (DIN), D89.2 (DOUT)
unnamed: D89.4 (DIN), D90.2 (DOUT)
unnamed: D90.4 (DIN), D91.2 (DOUT)
unnamed: D91.4 (DIN), D92.2 (DOUT)
unnamed: D92.4 (DIN), D93.2 (DOUT)
unnamed: D93.4 (DIN), D94.2 (DOUT)
unnamed: D94.4 (DIN), D95.2 (DOUT)
unnamed: D95.4 (DIN), D96.2 (DOUT)
unnamed: D96.4 (DIN), D97.2 (DOUT)
unnamed: D97.4 (DIN), D98.2 (DOUT)
unnamed: D98.4 (DIN), D99.2 (DOUT)
unnamed: D99.4 (DIN), D101.2 (DOUT)
unnamed: D102.2 (DOUT), D103.4 (DIN)
unnamed: D102.4 (DIN), D117.2 (DOUT)
unnamed: D103.2 (DOUT), D104.4 (DIN)
unnamed: D104.2 (DOUT), D105.4 (DIN)
unnamed: D105.2 (DOUT), D106.4 (DIN)
unnamed: D106.2 (DOUT), D107.4 (DIN)
unnamed: D107.2 (DOUT), D108.4 (DIN)
unnamed: D108.2 (DOUT), D109.4 (DIN)
unnamed: D109.2 (DOUT), D110.4 (DIN)
unnamed: D110.2 (DOUT), D111.4 (DIN)
unnamed: D111.2 (DOUT), D112.4 (DIN)
unnamed: D112.2 (DOUT), D113.4 (DIN)
unnamed: D113.2 (DOUT), D114.4 (DIN)
unnamed: D114.2 (DOUT), D115.4 (DIN)
unnamed: D115.2 (DOUT), D116.4 (DIN)
unnamed: D101.4 (DIN), D116.2 (DOUT)
unnamed: D117.4 (DIN), D132.2 (DOUT)
unnamed: D118.2 (DOUT), D134.4 (DIN)
unnamed: D118.4 (DIN), D119.2 (DOUT)
unnamed: D119.4 (DIN), D120.2 (DOUT)
unnamed: D120.4 (DIN), D121.2 (DOUT)
unnamed: D121.4 (DIN), D122.2 (DOUT)
unnamed: D122.4 (DIN), D123.2 (DOUT)
unnamed: D123.4 (DIN), D124.2 (DOUT)
unnamed: D124.4 (DIN), D125.2 (DOUT)
unnamed: D125.4 (DIN), D126.2 (DOUT)
unnamed: D126.4 (DIN), D127.2 (DOUT)
unnamed: D127.4 (DIN), D128.2 (DOUT)
unnamed: D128.4 (DIN), D129.2 (DOUT)
unnamed: D129.4 (DIN), D130.2 (DOUT)
unnamed: D130.4 (DIN), D131.2 (DOUT)
unnamed: D131.4 (DIN), D141.2 (DOUT)
unnamed: D132.4 (DIN), D133.2 (DOUT)
unnamed: D133.4 (DIN), D134.2 (DOUT)
unnamed: D135.2 (DOUT), D136.4 (DIN)
unnamed: D136.2 (DOUT), D137.4 (DIN)
unnamed: D137.2 (DOUT), D138.4 (DIN)
unnamed: D138.2 (DOUT), D139.4 (DIN)
unnamed: D139.2 (DOUT), D140.4 (DIN)
unnamed: D140.2 (DOUT), D141.4 (DIN)
Row1: S3.1, S8.1, S13.1, S18.1, S22.1, S27.1, S34.1, S40.1, S45.1, S49.1, S54.1, S60.1, S65.1, S72.1, S79.1; also elsewhere on the board
Row2: S4.1, S9.1, S14.1, S19.1, S23.1, S28.1, S35.1, S41.1, S46.1, S50.1, S55.1, S61.1, S66.1, S80.1; also elsewhere on the board
Row3: S5.1, S10.1, S15.1, S20.1, S24.1, S29.1, S36.1, S42.1, S47.1, S51.1, S56.1, S62.1, S67.1, S76.1, S81.1; also elsewhere on the board
Row4: S6.1, S11.1, S16.1, S21.1, S25.1, S30.1, S37.1, S43.1, S48.1, S52.1, S57.1, S63.1, S68.1, S77.1, S82.1; also elsewhere on the board
Row5: S7.1, S12.1, S17.1, S38.1, S58.1, S64.1, S69.1, S71.1, S78.1, S83.1; also elsewhere on the board
VCC: C12.1, C13.1, C14.1, C15.1, C16.1, C17.1, C18.1, C19.1, C20.1, C21.1, C22.1, C23.1, C24.1, C25.1, C26.1, C27.1, C28.1, C29.1, C30.1, C31.1, C32.1, C33.1, C34.1, C35.1, C36.1, C37.1, C38.1, C39.1, C41.1, C42.1, C43.1, C44.1, C45.1, C46.1, C47.1, C48.1, C49.1, C50.1, C51.1, C52.1, C53.1, C54.1, C55.1, C56.1, C57.1, C58.1, C59.1, C60.1, C61.1, C62.1, C63.1, C64.1, C65.1, C66.1, C67.1, C68.1, C69.1, C70.1, C71.1, C72.1, C73.1, C74.1, C75.1, C76.1, C77.1, C78.1, C79.1, C80.1, C81.1, D38.1 (VDD), D62.1 (VDD), D74.1 (VDD), D75.1 (VDD), D76.1 (VDD), D77.1 (VDD), D78.1 (VDD), D79.1 (VDD), D80.1 (VDD), D81.1 (VDD), D82.1 (VDD), D83.1 (VDD), D84.1 (VDD), D85.1 (VDD), D86.1 (VDD), D87.1 (VDD), D88.1 (VDD), D89.1 (VDD), D90.1 (VDD), D91.1 (VDD), D92.1 (VDD), D93.1 (VDD), D94.1 (VDD), D95.1 (VDD), D96.1 (VDD), D97.1 (VDD), D98.1 (VDD), D99.1 (VDD), D101.1 (VDD), D102.1 (VDD), D103.1 (VDD), D104.1 (VDD), D105.1 (VDD), D106.1 (VDD), D107.1 (VDD), D108.1 (VDD), D109.1 (VDD), D110.1 (VDD), D111.1 (VDD), D112.1 (VDD), D113.1 (VDD), D114.1 (VDD), D115.1 (VDD), D116.1 (VDD), D117.1 (VDD), D118.1 (VDD), D119.1 (VDD), D120.1 (VDD), D121.1 (VDD), D122.1 (VDD), D123.1 (VDD), D124.1 (VDD), D125.1 (VDD), D126.1 (VDD), D127.1 (VDD), D128.1 (VDD), D129.1 (VDD), D130.1 (VDD), D131.1 (VDD), D132.1 (VDD), D133.1 (VDD), D134.1 (VDD), D135.1 (VDD), D136.1 (VDD), D137.1 (VDD), D138.1 (VDD), D139.1 (VDD), D140.1 (VDD), D141.1 (VDD); also elsewhere on the board

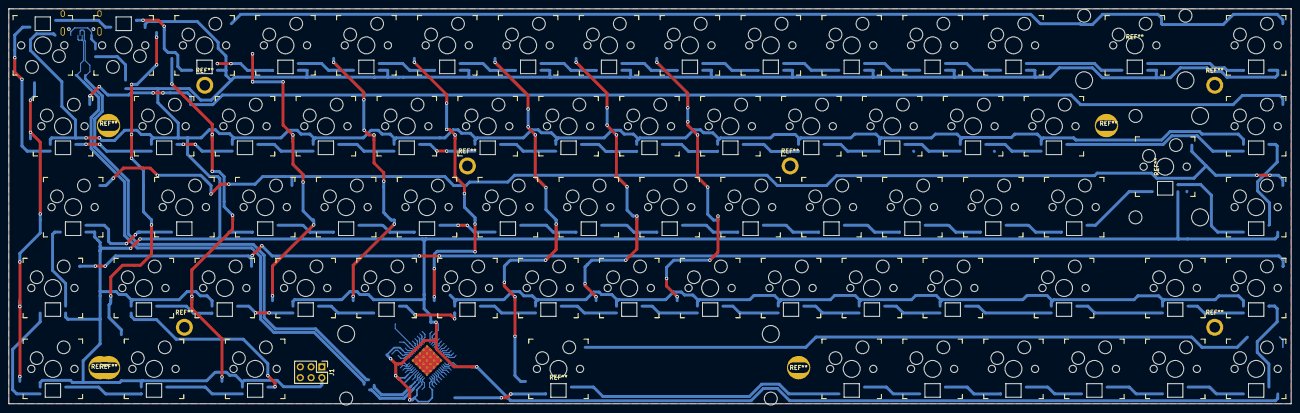
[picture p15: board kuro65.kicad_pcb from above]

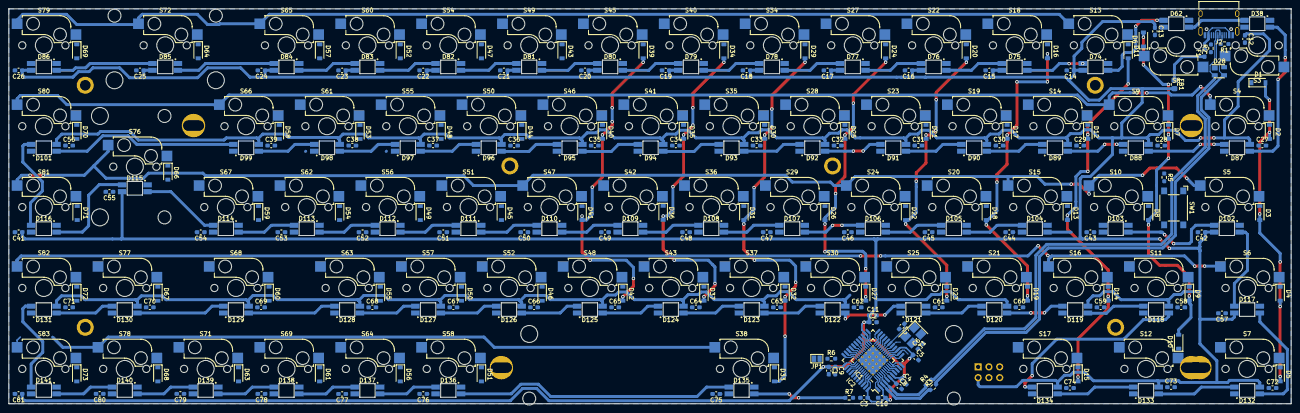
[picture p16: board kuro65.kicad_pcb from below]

Board: 2 copper layers, 302.0 x 93.0 mm, 304 parts (165 on the bottom side), 179 nets.

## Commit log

2021-02-06 Initial commit of existing files
    [kuro65.kicad_pcb, kuro65.sch, switches.sch]
2021-02-06 Added credits and acknowledgements
    [kuro65.kicad_pcb]
2021-02-06 Initial component placement done
    [kuro65.kicad_pcb, kuro65.sch]
2021-02-11 Some routing done + References added
    [kuro65.kicad_pcb, kuro65.sch, plate-65.dxf]
2021-02-12 Routing completed. Some modifications still needed.
    [kuro65.kicad_pcb, kuro65.sch]
2021-02-12 Added logo to project and placed on PCB.
    [kuro65.kicad_pcb]
2021-02-13 Some PCB adjustments.
    [USB4085-GF-A.stl, kuro65.kicad_pcb]
2021-02-13 Updated README with BOM
2021-02-14 Exchanged diode footpint to SOD-323
    [BOM.xlsx, kuro65.kicad_pcb, switches.sch]
2021-02-14 Added additional logos and some 3D render pictures
    [kuro65.kicad_pcb]
2021-02-20 Added schematic pictures
    [kuro65.sch, switches.sch]
2021-02-20 Updated README and added schematic pictures.
2022-08-14 Exchanged old lib folder with kicad_lib repo. Upgraded Kicad files to version 6.
    [kuro65.kicad_pcb, kuro65.kicad_sch, switches.kicad_sch]
2022-08-14 Updated kicad_lib to most recent version.
2022-08-14 Changed schematic and PCB layout for kuro65. Routing of PCB is incomplete.
    [kuro65.kicad_sch, switches.kicad_sch]
2022-08-14 Update kicad_libs pointer.
2022-08-14 Updates on PCB layout. Placement of LED components corrected.
    [kuro65.kicad_sch, switches.kicad_sch]
2022-11-18 Update README.md
    Added BOM section for JLCPCB SMT assembly
2022-11-23 Updated JLC BOM in README.md
2022-11-23 Updated PCB layout for DZ65 compatibility.
    [kuro65.kicad_sch]
2022-12-23 Updates in routed PCB.
    [kuro65.kicad_pcb, kuro65.kicad_sch, switches.kicad_sch]
2023-01-03 Initial routing completed. Need to clean up DRC and optimize board.
2023-01-03 Updated kicad_libs submodule to newest version.
2023-01-03 Updates on PCB, schematic and submodules.
    [kuro65.kicad_sch, switches.kicad_sch]
2023-01-03 Updated ground polygon on PCB.
2023-01-04 Updates to the PCB and the schematic.
    [kuro65.kicad_sch, switches.kicad_sch]
2023-01-04 Updated kicad_libs submodule.
2023-01-06 Added USB shield circuit to schematic and PCB.
    [BOM.xlsx, kuro65.kicad_sch]
2023-01-06 Updated routing of USB traces.
    [kuro65.kicad_sch]
2023-01-06 Updated JLC part numbers in schematic.
    [kuro65.kicad_sch]
2023-01-08 Updated PCB.
2023-01-13 Updated ground fill on PCB.
2023-01-13 Added BOM script for JLCPCB.
2023-02-17 Final design for first JLCPCB production run.
    [kuro65-B_Cu.gbl, kuro65-B_Mask.gbs, kuro65-B_Paste.gbp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]
2023-03-14 Updated schematic pictures and product pictures.
